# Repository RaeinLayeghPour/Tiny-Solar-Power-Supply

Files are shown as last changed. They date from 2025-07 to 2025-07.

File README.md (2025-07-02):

# Tiny-Solar-Power-Supply
Designed a compact solar power supply in KiCad for Toronto Metropolitan Formula Racing, featuring the AP3015 boost converter for voltage regulation, SS14 Schottky diodes for input/output protection, and a 2N7002 MOSFET for switching between solar and battery sources. The project includes a comprehensive schematic, PCB layout, 3D rendering, and organized source files, all fully optimized for low-voltage embedded systems and ready for fabrication.

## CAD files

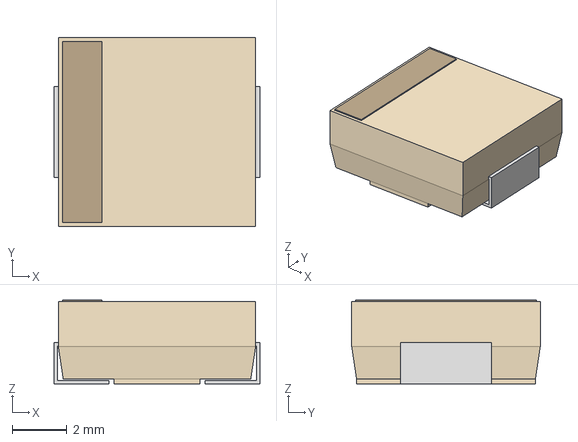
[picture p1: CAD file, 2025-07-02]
IND_ASPI-0630LR_ABR.step
7.49 x 6.86 x 3.05 mm

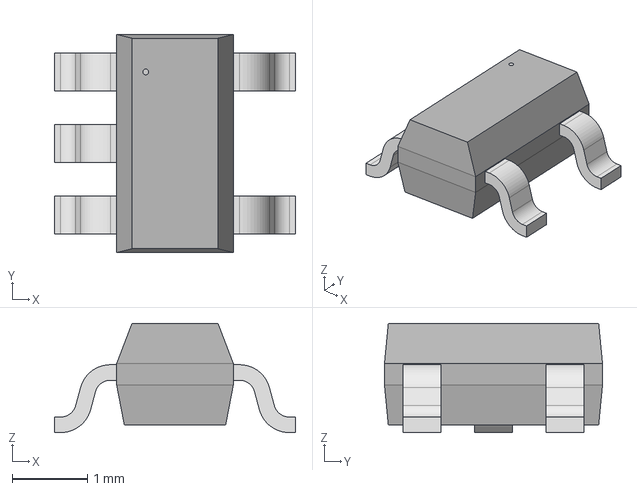
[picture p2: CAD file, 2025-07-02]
SOT23-5_1P55X2P9_DIO.step
3.20 x 2.90 x 1.45 mm

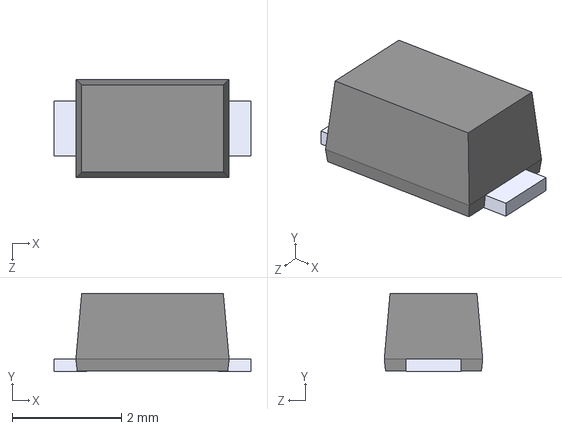
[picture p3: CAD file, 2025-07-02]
SS14.step
3.60 x 1.43 x 1.80 mm

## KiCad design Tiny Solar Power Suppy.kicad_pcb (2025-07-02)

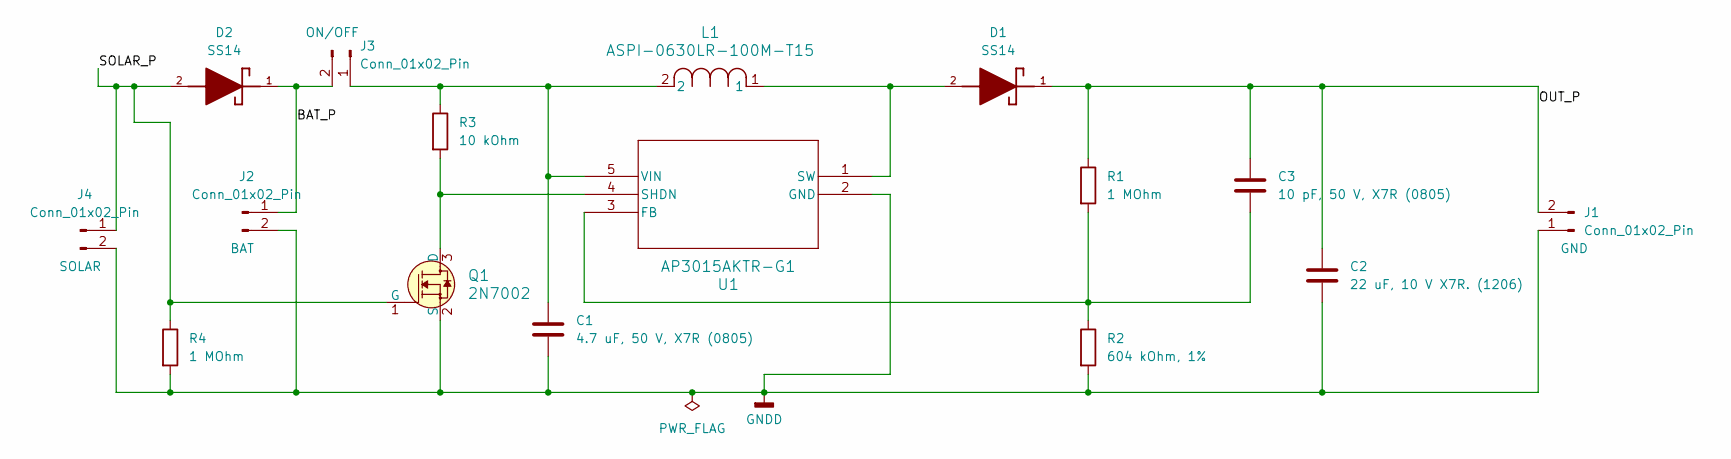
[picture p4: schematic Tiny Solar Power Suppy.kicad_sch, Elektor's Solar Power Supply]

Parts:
C1: 4.7 uF, 50 V, X7R (0805); C_0805_2012Metric
C2: 22 uF, 10 V X7R. (1206); C_1206_3216Metric
C3: 10 pF, 50 V, X7R (0805); C_0805_2012Metric
D1, D2: SS14; DIOM5227X270N; MOUSER_PART_NUMBER 512-SS14
J1, J2, J3: Conn_01x02_Pin; PinHeader_1x02_P2.54mm_Vertical
J4: Conn_01x02_Pin; PinHeader_1x02_P2.54mm_Horizontal
L1: ASPI-0630LR-100M-T15; IND_ASPI-0630LR_ABR
Q1: 2N7002; SOT-23-3; MPN 2N7002; Digi-Key_PN 2N7002NCT-ND
R1, R4: 1 MOhm; R_0805_2012Metric
R2: 604 kOhm, 1%; R_0805_2012Metric
R3: 10 kOhm; R_0805_2012Metric
U1: AP3015AKTR-G1; SOT23-5_1P55X2P9_DIO

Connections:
/BAT_P: D2.1, J2.1, J3.2
/OUT_P: C2.1, C3.1, D1.1, J1.2, R1.1
/SOLAR_P: D2.2, J4.1, Q1.1 (G), R4.1
GNDD: C1.2, C2.2, J1.1, J2.2, J4.2, Q1.2 (S), R2.2, R4.2, U1.2 (GND)
unnamed: C1.1, J3.1, L1.2, R3.1, U1.5 (VIN)
unnamed: Q1.3 (D), R3.2, U1.4 (SHDN)
unnamed: C3.2, R1.2, R2.1, U1.3 (FB)
unnamed: D1.2, L1.1, U1.1 (SW)

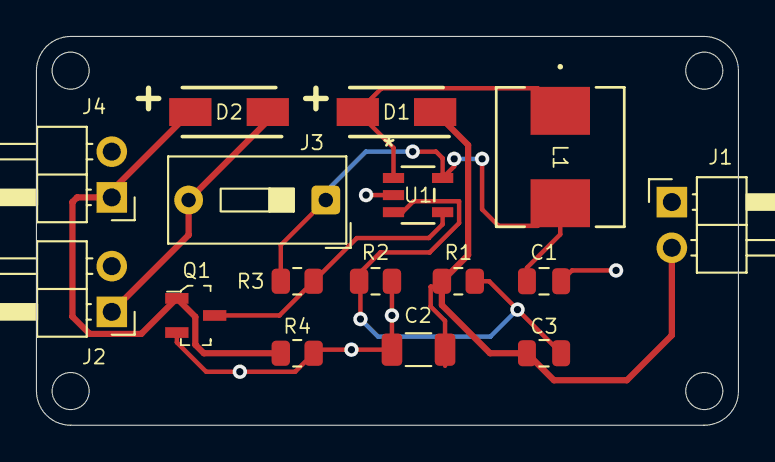
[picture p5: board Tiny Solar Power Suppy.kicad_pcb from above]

Board: 2 copper layers, 39.0 x 21.6 mm, 16 parts (0 on the bottom side), 8 nets.
